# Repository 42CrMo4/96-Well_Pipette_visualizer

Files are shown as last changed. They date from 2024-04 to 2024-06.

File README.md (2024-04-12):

# KiCad_Template

This is a template repo for KiCAD v6 projects with 

### Goal & Status
| undefined | learn | prototype | 80-20-rule | polished Product |
|---|---|---|---|---|
| not known what the project will bring | personally learn something new (function, design, process) otherwise no usefull outcome expected | a working prototype or mvp | 80% outcome with 20% effort. Dont expect a finished product. | - |

| idea | design | implementation | testing | finished |
|---|---|---|---|---|
| brainstorming workflow | putting together a goal list, architecture, hig level | schematic, pcb | | |

## Todo

* ~add DRC, ERC as seperate WF~ 
* ~add DRC, ERC to release WF as blocking~
* ~add release checklist~
* order release checklist
* ~add workflow to automatically create new realease checklist and realease note file and reset the generic for the next release~
* ~Rename artefacts with project name and date?~
* Add diffrent PCB manufactures output via kibot
* ~Update to kicad6_auto:1.3.0~
* use version number for template

## Usage

hit "use this template" button
delet all unneded files in Doc folder
delet all Schematic stuff but not the text Placeholders <<...>>
delet all PCB stuff but not the text Placeholders <<...>> and the Board Edge (or the iBOM will fail). You can remodel it later.

### Workflow
If not working:
setting -> action -> general -> Workflow permissions -> Read and write permissions

## working

in the first workflow run the action will create a new branch "documentation" to store the newest PCBdraw pictures. 
Each action run will force push the png to this branch. So so not use the Fabrication folder in the documentation branch.

## Description. 

| Font | Back |
|---|---|
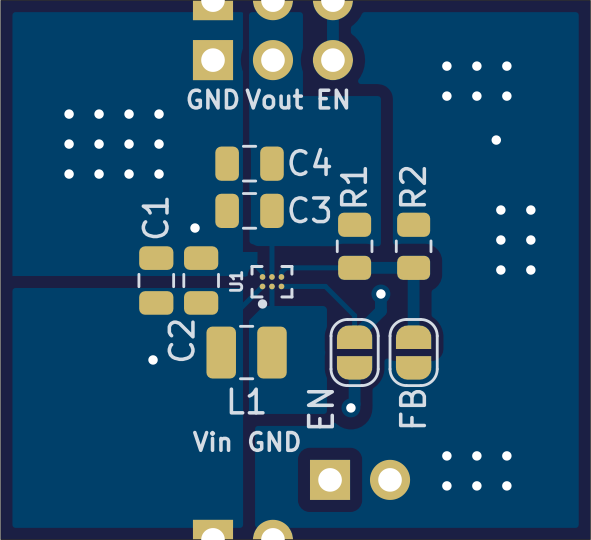
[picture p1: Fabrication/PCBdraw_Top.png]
PCB Top design
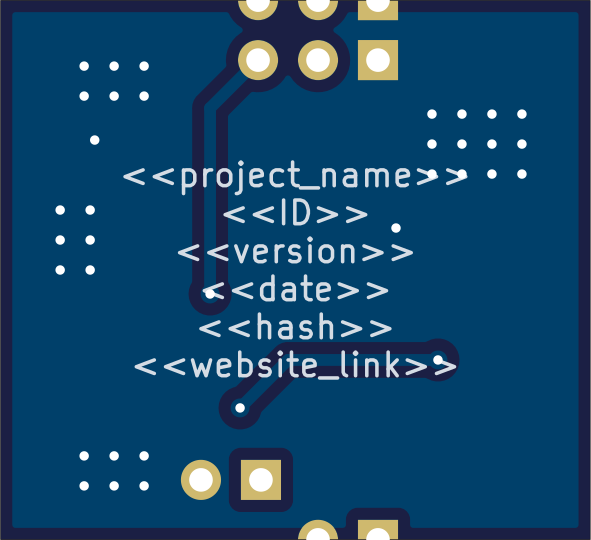
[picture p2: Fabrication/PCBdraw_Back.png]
PCB Back design
|  |  |

Link to the current BOM

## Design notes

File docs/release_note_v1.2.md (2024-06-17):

| Font | Back |
| --- | --- |
|PCB Top design|PCB Back design|

change usb-c shield pads to no net to make kicad happy

Changes
* change usb-c shield pads to <no_net>

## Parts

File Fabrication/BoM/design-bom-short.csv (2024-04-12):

Row | Description | Part | References | Value | Footprint | Quantity Per PCB | Status | Datasheet | STANDARD | PARTREV | MAXIMUM_PACKAGE_HEIGHT | MANUFACTURER
1 | Unpolarized capacitor, small symbol | C_Small | C1 C2 C3 C4 | C_Small | C_0805_2012Metric | 4 |  | ~
2 | Generic connector, single row, 01x02, script generated (kicad-library-utils/schlib/autogen/connector/) | Conn_01x02 | J1 J2 | Conn_01x02 | PinHeader_1x02_P2.54mm_Vertical | 2 |  | ~
3 | Generic connector, single row, 01x03, script generated (kicad-library-utils/schlib/autogen/connector/) | Conn_01x03 | J3 J4 | Conn_01x03 | PinHeader_1x03_P2.54mm_Vertical | 2 |  | ~
4 | Inductor, small symbol | L_Small | L1 | L_Small | L_1008_2520Metric | 1 |  | ~
5 | Resistor, small symbol | R_Small | R1 R2 | R_Small | R_0805_2012Metric | 2 |  | ~
6 |  | TPS61099YFFT | U1 | TPS61099YFFT | BGA6N40P3X2_122X88X62N | 1 |  |  | IPC 7351B | K | 0.625mm | Texas Instruments

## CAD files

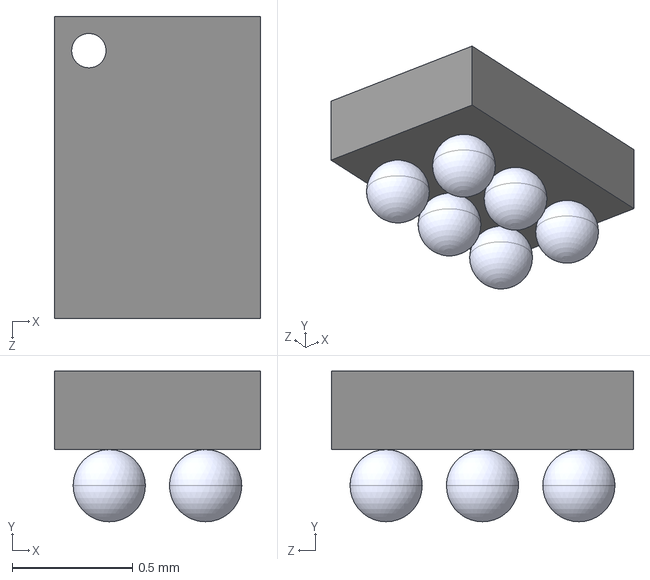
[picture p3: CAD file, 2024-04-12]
3d-models/TPS61099xYFFT.step
0.855 x 0.625 x 1.26 mm

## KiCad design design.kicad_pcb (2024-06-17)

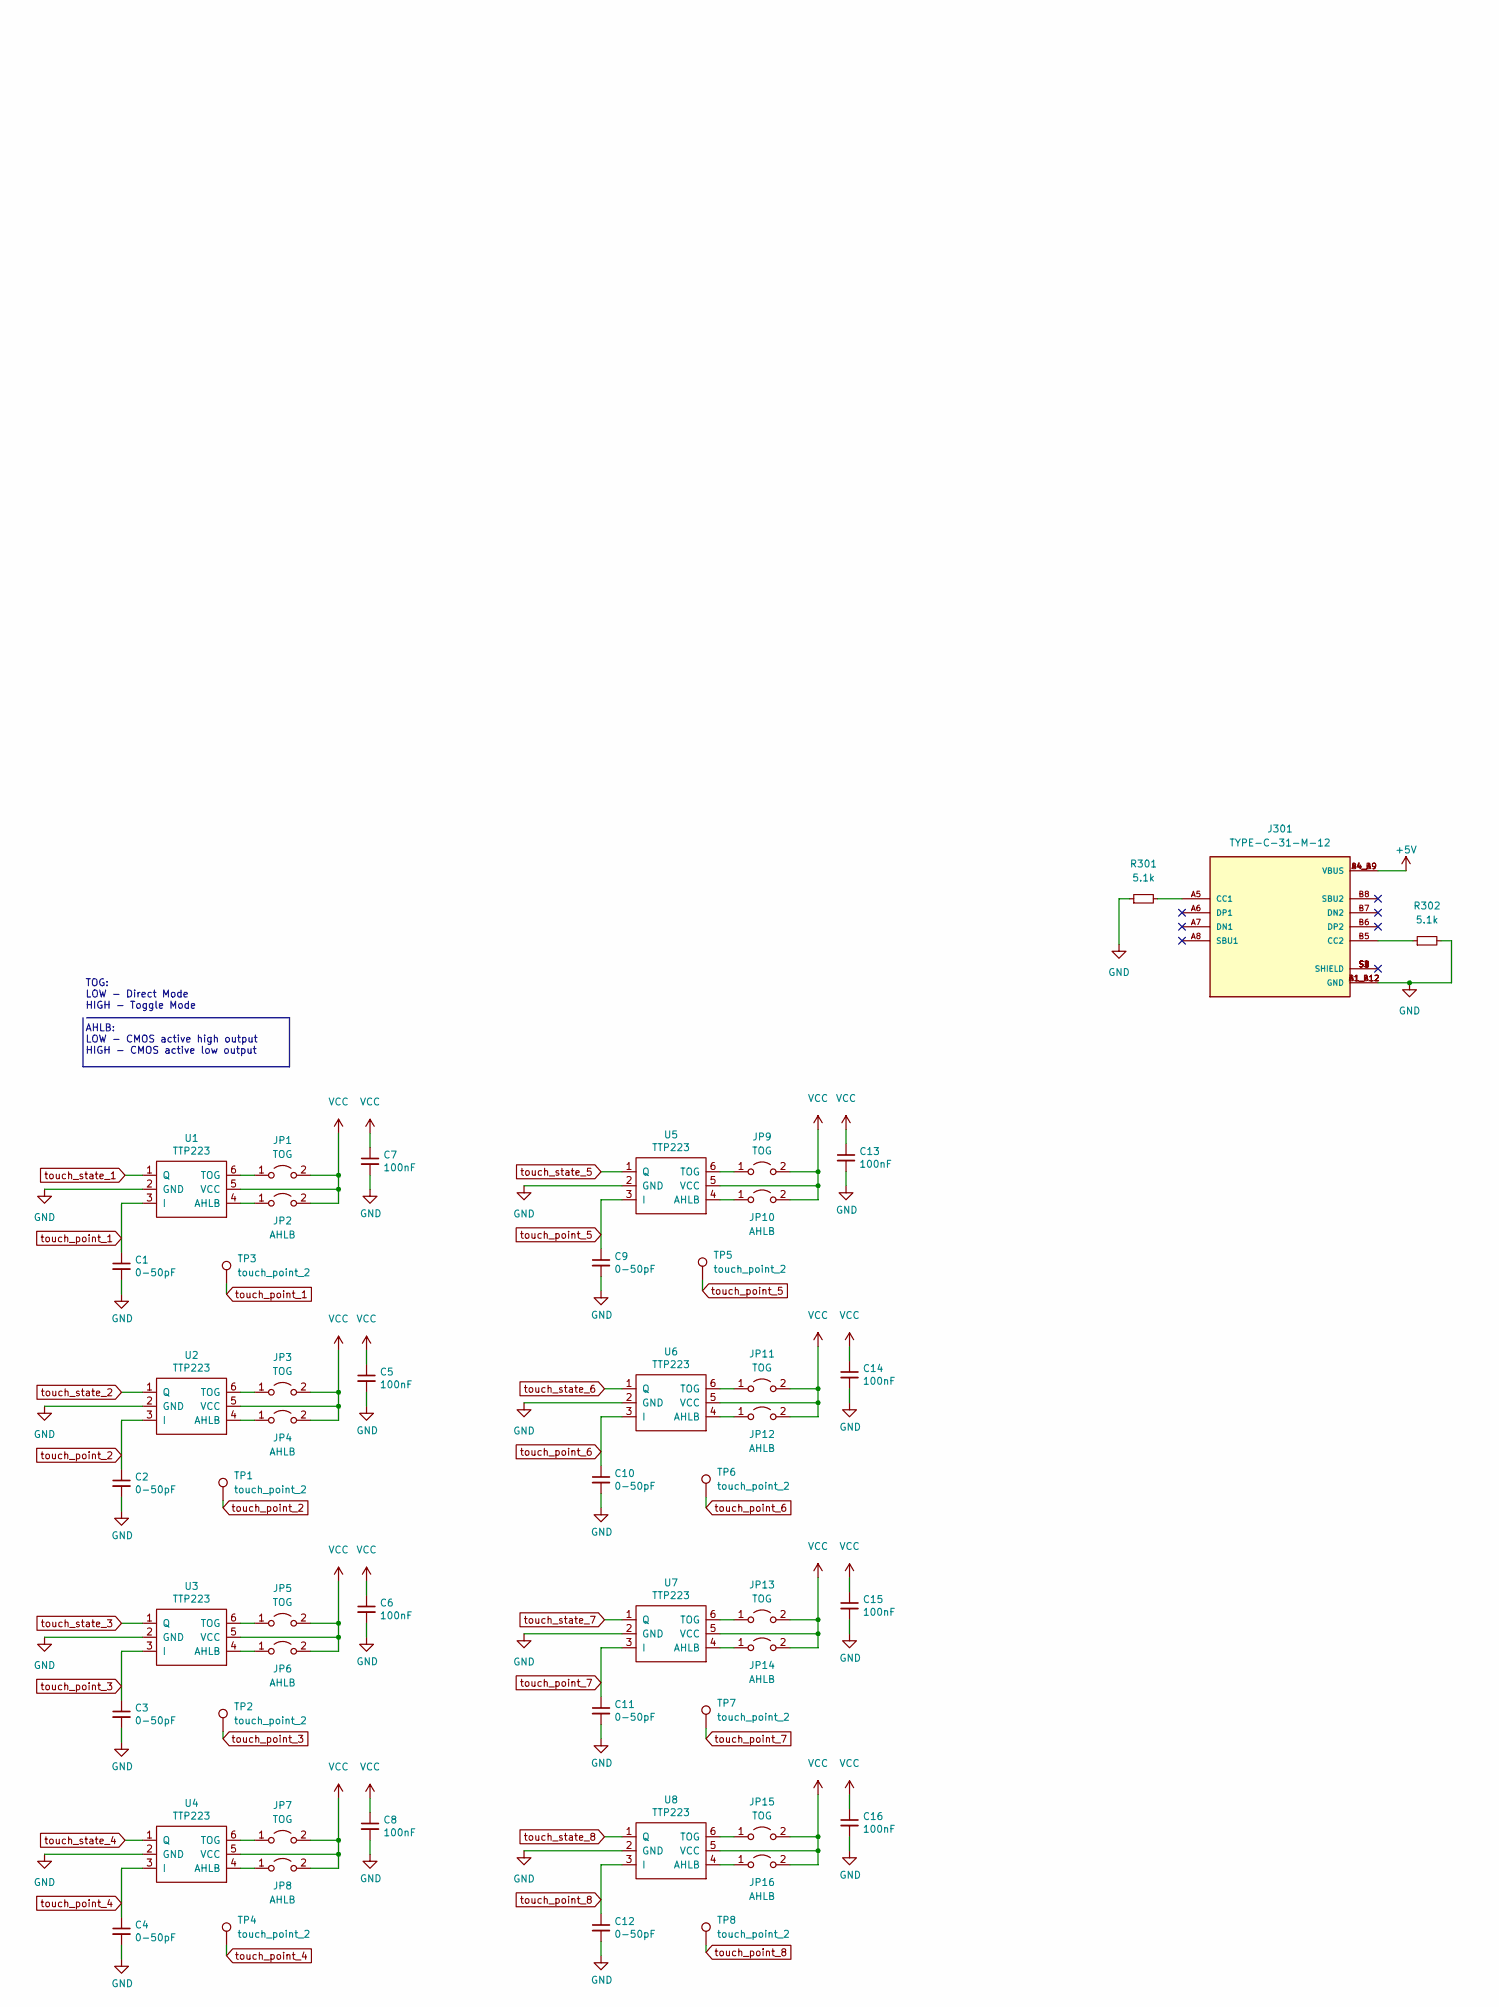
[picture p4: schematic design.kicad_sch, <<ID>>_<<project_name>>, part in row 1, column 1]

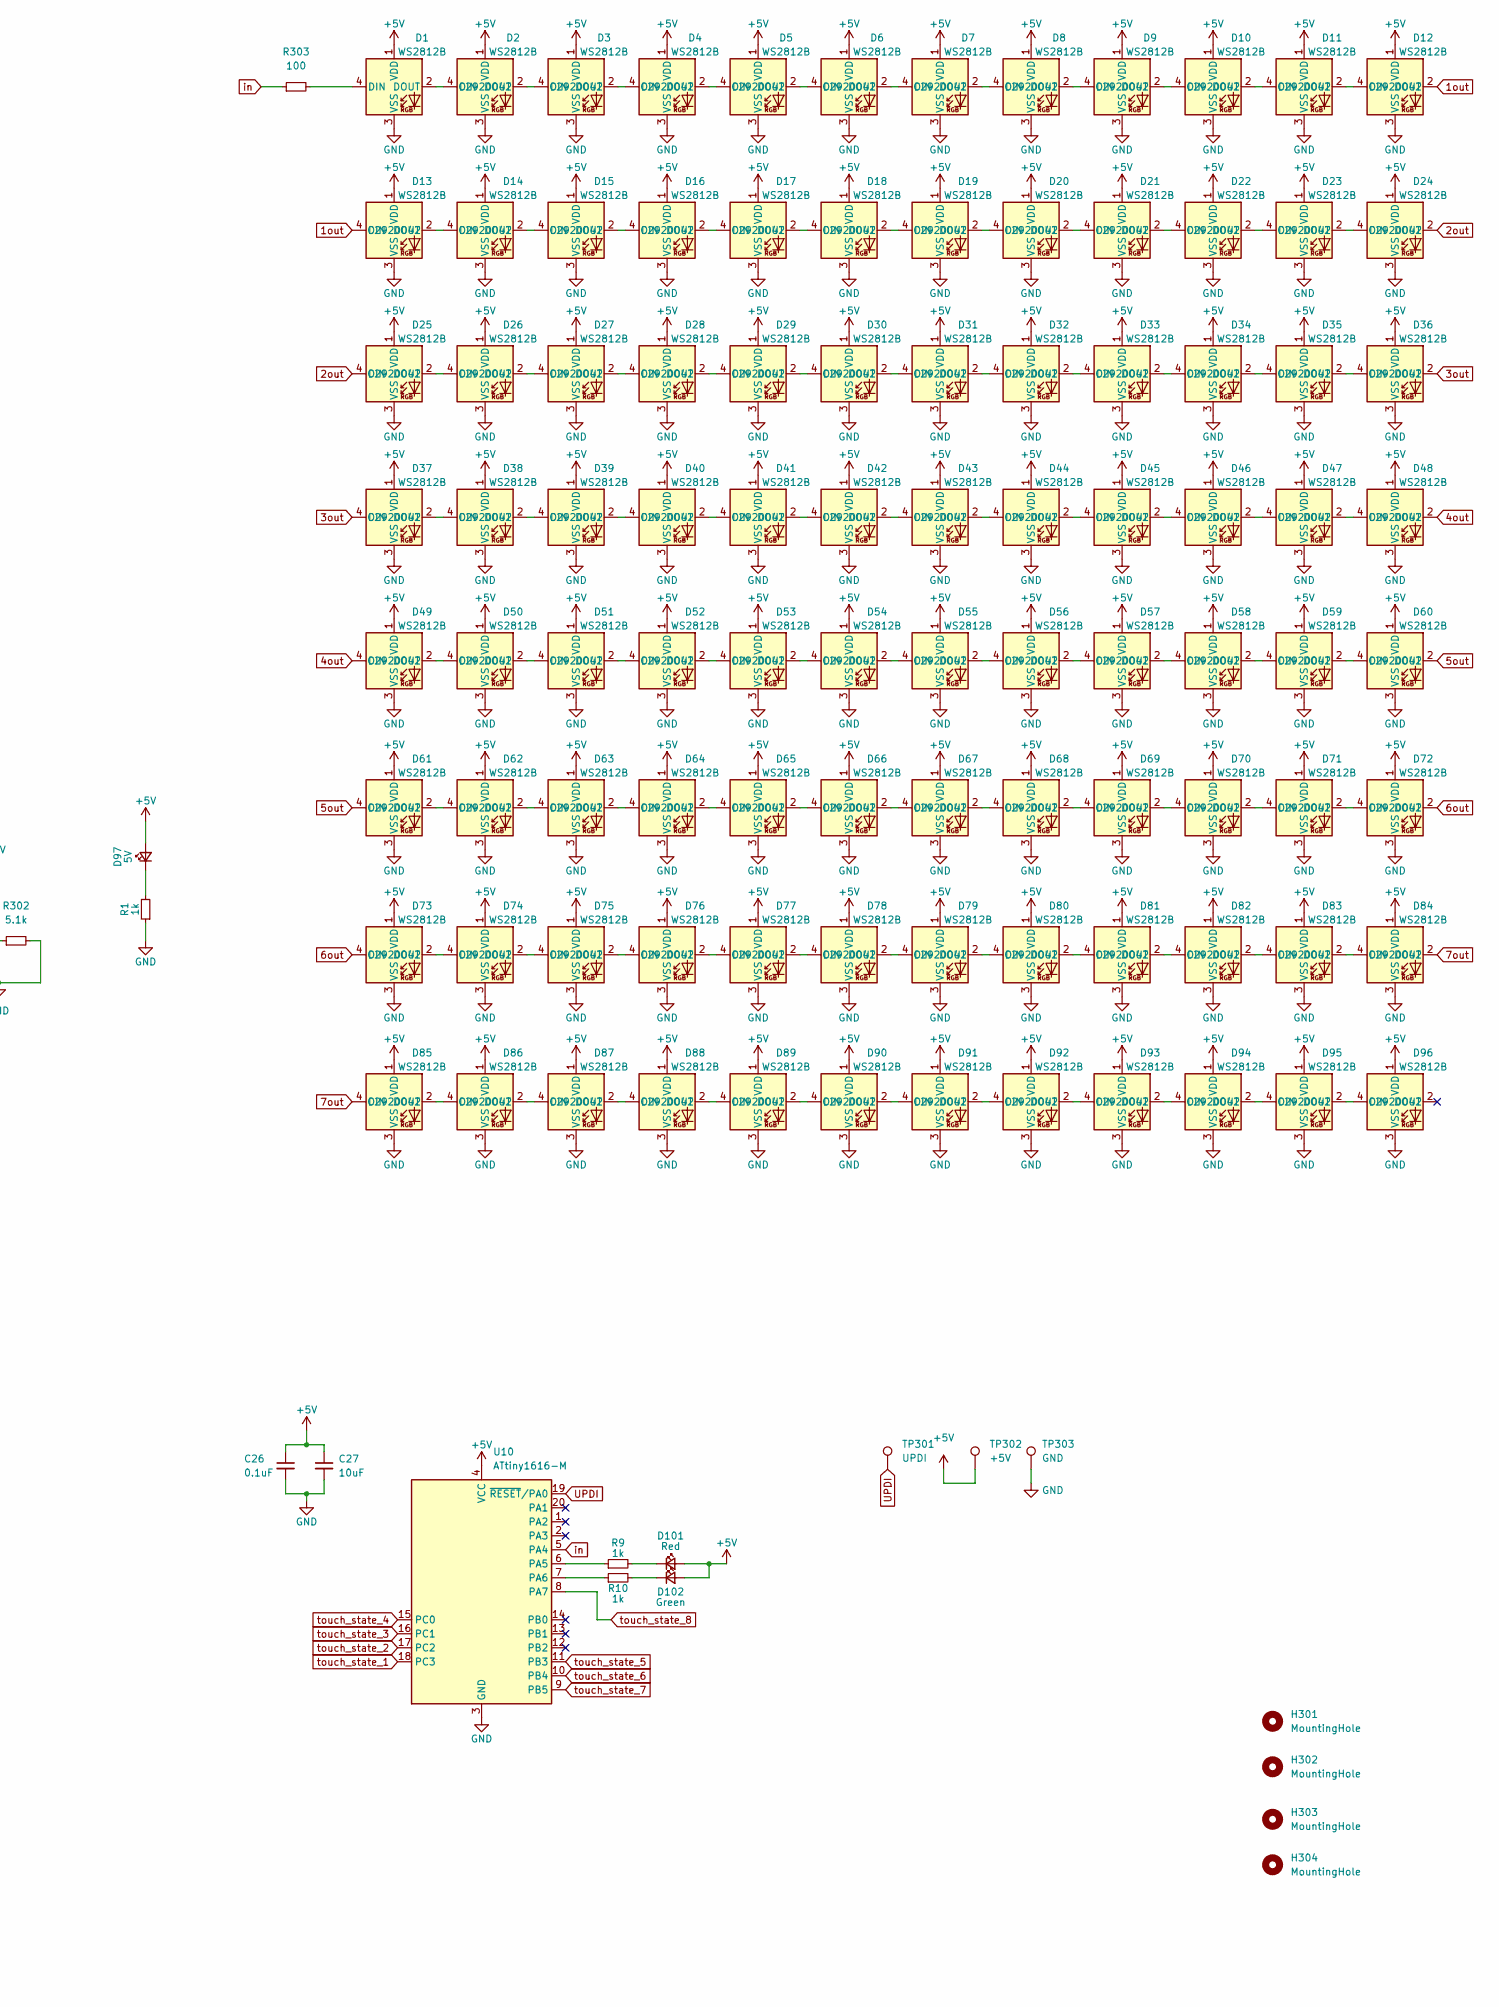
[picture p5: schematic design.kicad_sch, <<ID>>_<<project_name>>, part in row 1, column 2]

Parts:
C1, C2, C3, C4, C9, C10, C11, C12: 0-50pF; C_0805_2012Metric
C5, C6, C7, C8, C13, C14, C15, C16: 100nF; C_0805_2012Metric
C26: 0.1uF; C_0805_2012Metric
C27: 10uF; C_0805_2012Metric
D1, D2, D3, D4, D5, D6, D7, D8, D9, D10, D11, D12, D13, D14, D15, D16, D17, D18, D19, D20, D21, D22, D23, D24, D25, D26, D27, D28, D29, D30, D31, D32, D33, D34, D35, D36, D37, D38, D39, D40, D41, D42, D43, D44, D45, D46, D47, D48, D49, D50, D51, D52, D53, D54, D55, D56, D57, D58, D59, D60, D61, D62, D63, D64, D65, D66, D67, D68, D69, D70, D71, D72, D73, D74, D75, D76, D77, D78, D79, D80, D81, D82, D83, D84, D85, D86, D87, D88, D89, D90, D91, D92, D93, D94, D95, D96: WS2812B; LED_WS2812B_PLCC4_5.0x5.0mm_P3.2mm; LCSC C2920042
D97: 5V; LED_0603_1608Metric
D101: Red; LED_0603_1608Metric
D102: Green; LED_0603_1608Metric
H301, H302, H303, H304: MountingHole; MountingHole_2.7mm_M2.5
J301: TYPE-C-31-M-12; TYPE-C-31-M-12_HRO_TYPE-C-31-M-12; PARTREV 2020.12.08
JP1, JP3, JP5, JP7, JP9, JP11, JP13, JP15: TOG; SolderJumper-2_P1.3mm_Open_RoundedPad1.0x1.5mm
JP2, JP4, JP6, JP8, JP10, JP12, JP14, JP16: AHLB; SolderJumper-2_P1.3mm_Open_RoundedPad1.0x1.5mm
R1, R9, R10: 1k; R_0805_2012Metric
R301, R302: 5.1k; R_0805_2012Metric
R303: 100; R_0805_2012Metric
TP1, TP2, TP3, TP4, TP5, TP6, TP7, TP8: touch_point_2
TP301: UPDI; TestPoint_Pad_3.0x3.0mm
TP302: +5V; TestPoint_Pad_3.0x3.0mm
TP303: GND; TestPoint_Pad_3.0x3.0mm
U1, U2, U3, U4, U5, U6, U7, U8: TTP223; SOT-23-6
U10: ATtiny1616-M; VQFN-20-1EP_3x3mm_P0.4mm_EP1.7x1.7mm

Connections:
1out: D12.2 (DOUT), D13.4 (DIN)
2out: D24.2 (DOUT), D25.4 (DIN)
3out: D36.2 (DOUT), D37.4 (DIN)
4out: D48.2 (DOUT), D49.4 (DIN)
5out: D60.2 (DOUT), D61.4 (DIN)
6out: D72.2 (DOUT), D73.4 (DIN)
7out: D84.2 (DOUT), D85.4 (DIN)
GND: C1.2, C2.2, C3.2, C4.2, C5.2, C6.2, C7.2, C8.2, C9.2, C10.2, C11.2, C12.2, C13.2, C14.2, C15.2, C16.2, C26.2, C27.2, D1.3 (VSS), D2.3 (VSS), D3.3 (VSS), D4.3 (VSS), D5.3 (VSS), D6.3 (VSS), D7.3 (VSS), D8.3 (VSS), D9.3 (VSS), D10.3 (VSS), D11.3 (VSS), D12.3 (VSS), D13.3 (VSS), D14.3 (VSS), D15.3 (VSS), D16.3 (VSS), D17.3 (VSS), D18.3 (VSS), D19.3 (VSS), D20.3 (VSS), D21.3 (VSS), D22.3 (VSS), D23.3 (VSS), D24.3 (VSS), D25.3 (VSS), D26.3 (VSS), D27.3 (VSS), D28.3 (VSS), D29.3 (VSS), D30.3 (VSS), D31.3 (VSS), D32.3 (VSS), D33.3 (VSS), D34.3 (VSS), D35.3 (VSS), D36.3 (VSS), D37.3 (VSS), D38.3 (VSS), D39.3 (VSS), D40.3 (VSS), D41.3 (VSS), D42.3 (VSS), D43.3 (VSS), D44.3 (VSS), D45.3 (VSS), D46.3 (VSS), D47.3 (VSS), D48.3 (VSS), D49.3 (VSS), D50.3 (VSS), D51.3 (VSS), D52.3 (VSS), D53.3 (VSS), D54.3 (VSS), D55.3 (VSS), D56.3 (VSS), D57.3 (VSS), D58.3 (VSS), D59.3 (VSS), D60.3 (VSS), D61.3 (VSS), D62.3 (VSS), D63.3 (VSS), D64.3 (VSS), D65.3 (VSS), D66.3 (VSS), D67.3 (VSS), D68.3 (VSS), D69.3 (VSS), D70.3 (VSS), D71.3 (VSS), D72.3 (VSS), D73.3 (VSS), D74.3 (VSS), D75.3 (VSS), D76.3 (VSS), D77.3 (VSS), D78.3 (VSS), D79.3 (VSS), D80.3 (VSS), D81.3 (VSS), D82.3 (VSS), D83.3 (VSS), D84.3 (VSS), D85.3 (VSS), D86.3 (VSS), D87.3 (VSS), D88.3 (VSS), D89.3 (VSS), D90.3 (VSS), D91.3 (VSS), D92.3 (VSS), D93.3 (VSS), D94.3 (VSS), D95.3 (VSS), D96.3 (VSS), J301.A1_B12 (GND), J301.B1_A12 (GND), R1.1, R301.1, R302.2, TP303.1, U1.2 (GND), U2.2 (GND), U3.2 (GND), U4.2 (GND), U5.2 (GND), U6.2 (GND), U7.2 (GND), U8.2 (GND), U10.3 (GND), U10.21 (GND)
unnamed: D1.2 (DOUT), D2.4 (DIN)
unnamed: D1.4 (DIN), R303.2
unnamed: D2.2 (DOUT), D3.4 (DIN)
unnamed: D3.2 (DOUT), D4.4 (DIN)
unnamed: D4.2 (DOUT), D5.4 (DIN)
unnamed: D5.2 (DOUT), D6.4 (DIN)
unnamed: D6.2 (DOUT), D7.4 (DIN)
unnamed: D7.2 (DOUT), D8.4 (DIN)
unnamed: D8.2 (DOUT), D9.4 (DIN)
unnamed: D10.2 (DOUT), D11.4 (DIN)
unnamed: D9.2 (DOUT), D10.4 (DIN)
unnamed: D11.2 (DOUT), D12.4 (DIN)
unnamed: D13.2 (DOUT), D14.4 (DIN)
unnamed: D14.2 (DOUT), D15.4 (DIN)
unnamed: D15.2 (DOUT), D16.4 (DIN)
unnamed: D16.2 (DOUT), D17.4 (DIN)
unnamed: D17.2 (DOUT), D18.4 (DIN)
unnamed: D18.2 (DOUT), D19.4 (DIN)
unnamed: D19.2 (DOUT), D20.4 (DIN)
unnamed: D20.2 (DOUT), D21.4 (DIN)
unnamed: D21.2 (DOUT), D22.4 (DIN)
unnamed: D22.2 (DOUT), D23.4 (DIN)
unnamed: D23.2 (DOUT), D24.4 (DIN)
unnamed: D25.2 (DOUT), D26.4 (DIN)
unnamed: D26.2 (DOUT), D27.4 (DIN)
unnamed: D27.2 (DOUT), D28.4 (DIN)
unnamed: D28.2 (DOUT), D29.4 (DIN)
unnamed: D29.2 (DOUT), D30.4 (DIN)
unnamed: D30.2 (DOUT), D31.4 (DIN)
unnamed: D31.2 (DOUT), D32.4 (DIN)
unnamed: D32.2 (DOUT), D33.4 (DIN)
unnamed: D33.2 (DOUT), D34.4 (DIN)
unnamed: D34.2 (DOUT), D35.4 (DIN)
unnamed: D35.2 (DOUT), D36.4 (DIN)
unnamed: D37.2 (DOUT), D38.4 (DIN)
unnamed: D38.2 (DOUT), D39.4 (DIN)
unnamed: D39.2 (DOUT), D40.4 (DIN)
unnamed: D40.2 (DOUT), D41.4 (DIN)
unnamed: D41.2 (DOUT), D42.4 (DIN)
unnamed: D42.2 (DOUT), D43.4 (DIN)
unnamed: D43.2 (DOUT), D44.4 (DIN)
unnamed: D44.2 (DOUT), D45.4 (DIN)
unnamed: D45.2 (DOUT), D46.4 (DIN)
unnamed: D46.2 (DOUT), D47.4 (DIN)
unnamed: D47.2 (DOUT), D48.4 (DIN)
unnamed: D49.2 (DOUT), D50.4 (DIN)
unnamed: D50.2 (DOUT), D51.4 (DIN)
unnamed: D51.2 (DOUT), D52.4 (DIN)
unnamed: D52.2 (DOUT), D53.4 (DIN)
unnamed: D53.2 (DOUT), D54.4 (DIN)
unnamed: D54.2 (DOUT), D55.4 (DIN)
unnamed: D55.2 (DOUT), D56.4 (DIN)
unnamed: D56.2 (DOUT), D57.4 (DIN)
unnamed: D57.2 (DOUT), D58.4 (DIN)
unnamed: D58.2 (DOUT), D59.4 (DIN)
unnamed: D59.2 (DOUT), D60.4 (DIN)
unnamed: D61.2 (DOUT), D62.4 (DIN)
unnamed: D62.2 (DOUT), D63.4 (DIN)
unnamed: D63.2 (DOUT), D64.4 (DIN)
unnamed: D64.2 (DOUT), D65.4 (DIN)
unnamed: D65.2 (DOUT), D66.4 (DIN)
unnamed: D66.2 (DOUT), D67.4 (DIN)
unnamed: D67.2 (DOUT), D68.4 (DIN)
unnamed: D68.2 (DOUT), D69.4 (DIN)
unnamed: D69.2 (DOUT), D70.4 (DIN)
unnamed: D70.2 (DOUT), D71.4 (DIN)
unnamed: D71.2 (DOUT), D72.4 (DIN)
unnamed: D73.2 (DOUT), D74.4 (DIN)
unnamed: D74.2 (DOUT), D75.4 (DIN)
unnamed: D75.2 (DOUT), D76.4 (DIN)
unnamed: D76.2 (DOUT), D77.4 (DIN)
unnamed: D77.2 (DOUT), D78.4 (DIN)
unnamed: D78.2 (DOUT), D79.4 (DIN)
unnamed: D79.2 (DOUT), D80.4 (DIN)
unnamed: D80.2 (DOUT), D81.4 (DIN)
unnamed: D81.2 (DOUT), D82.4 (DIN)
unnamed: D82.2 (DOUT), D83.4 (DIN)
unnamed: D83.2 (DOUT), D84.4 (DIN)
unnamed: D85.2 (DOUT), D86.4 (DIN)
unnamed: D86.2 (DOUT), D87.4 (DIN)
unnamed: D87.2 (DOUT), D88.4 (DIN)
unnamed: D88.2 (DOUT), D89.4 (DIN)
unnamed: D89.2 (DOUT), D90.4 (DIN)
unnamed: D90.2 (DOUT), D91.4 (DIN)
unnamed: D91.2 (DOUT), D92.4 (DIN)
unnamed: D92.2 (DOUT), D93.4 (DIN)
unnamed: D93.2 (DOUT), D94.4 (DIN)
unnamed: D94.2 (DOUT), D95.4 (DIN)
unnamed: D95.2 (DOUT), D96.4 (DIN)
unnamed: D97.1 (K), R1.2
unnamed: D101.1 (K), R9.2
unnamed: D102.1 (K), R10.2
unnamed: J301.A5 (CC1), R301.2
unnamed: J301.B5 (CC2), R302.1
unnamed: JP1.1 (A), U1.6 (TOG)
unnamed: JP2.1 (A), U1.4 (AHLB)
unnamed: JP3.1 (A), U2.6 (TOG)
unnamed: JP4.1 (A), U2.4 (AHLB)
unnamed: JP5.1 (A), U3.6 (TOG)
unnamed: JP6.1 (A), U3.4 (AHLB)
unnamed: JP7.1 (A), U4.6 (TOG)
unnamed: JP8.1 (A), U4.4 (AHLB)
unnamed: JP9.1 (A), U5.6 (TOG)
unnamed: JP10.1 (A), U5.4 (AHLB)
unnamed: JP11.1 (A), U6.6 (TOG)
unnamed: JP12.1 (A), U6.4 (AHLB)
unnamed: JP13.1 (A), U7.6 (TOG)
unnamed: JP14.1 (A), U7.4 (AHLB)
unnamed: JP15.1 (A), U8.6 (TOG)
unnamed: JP16.1 (A), U8.4 (AHLB)
unnamed: R9.1, U10.6 (PA5)
unnamed: R10.1, U10.7 (PA6)
UPDI: TP301.1, U10.19 (~RESET/PA0)
in: R303.1, U10.5 (PA4)
touch_point_1: C1.1, TP3.1, U1.3 (I)
touch_point_2: C2.1, TP1.1, U2.3 (I)
touch_point_3: C3.1, TP2.1, U3.3 (I)
touch_point_4: C4.1, TP4.1, U4.3 (I)
touch_point_5: C9.1, TP5.1, U5.3 (I)
touch_point_6: C10.1, TP6.1, U6.3 (I)
touch_point_7: C11.1, TP7.1, U7.3 (I)
touch_point_8: C12.1, TP8.1, U8.3 (I)
touch_state_1: U1.1 (Q), U10.18 (PC3)
touch_state_2: U2.1 (Q), U10.17 (PC2)
touch_state_3: U3.1 (Q), U10.16 (PC1)
touch_state_4: U4.1 (Q), U10.15 (PC0)
touch_state_5: U5.1 (Q), U10.11 (PB3)
touch_state_6: U6.1 (Q), U10.10 (PB4)
touch_state_7: U7.1 (Q), U10.9 (PB5)
touch_state_8: U8.1 (Q), U10.8 (PA7)

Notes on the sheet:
TOG: LOW - Direct Mode HIGH - Toggle Mode AHLB: LOW - CMOS active high output HIGH - CMOS active low output

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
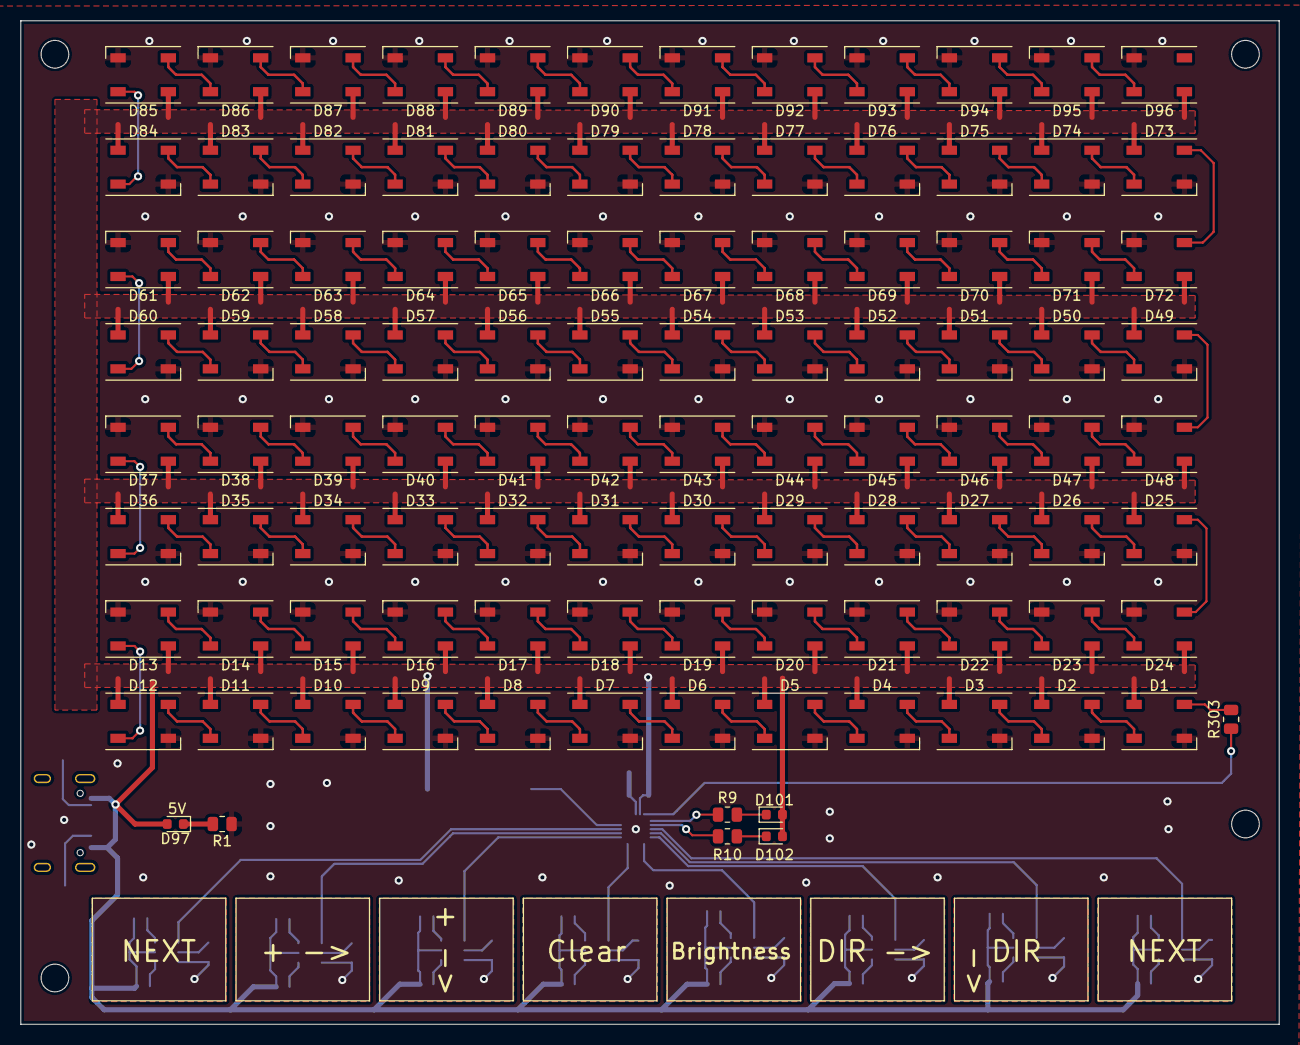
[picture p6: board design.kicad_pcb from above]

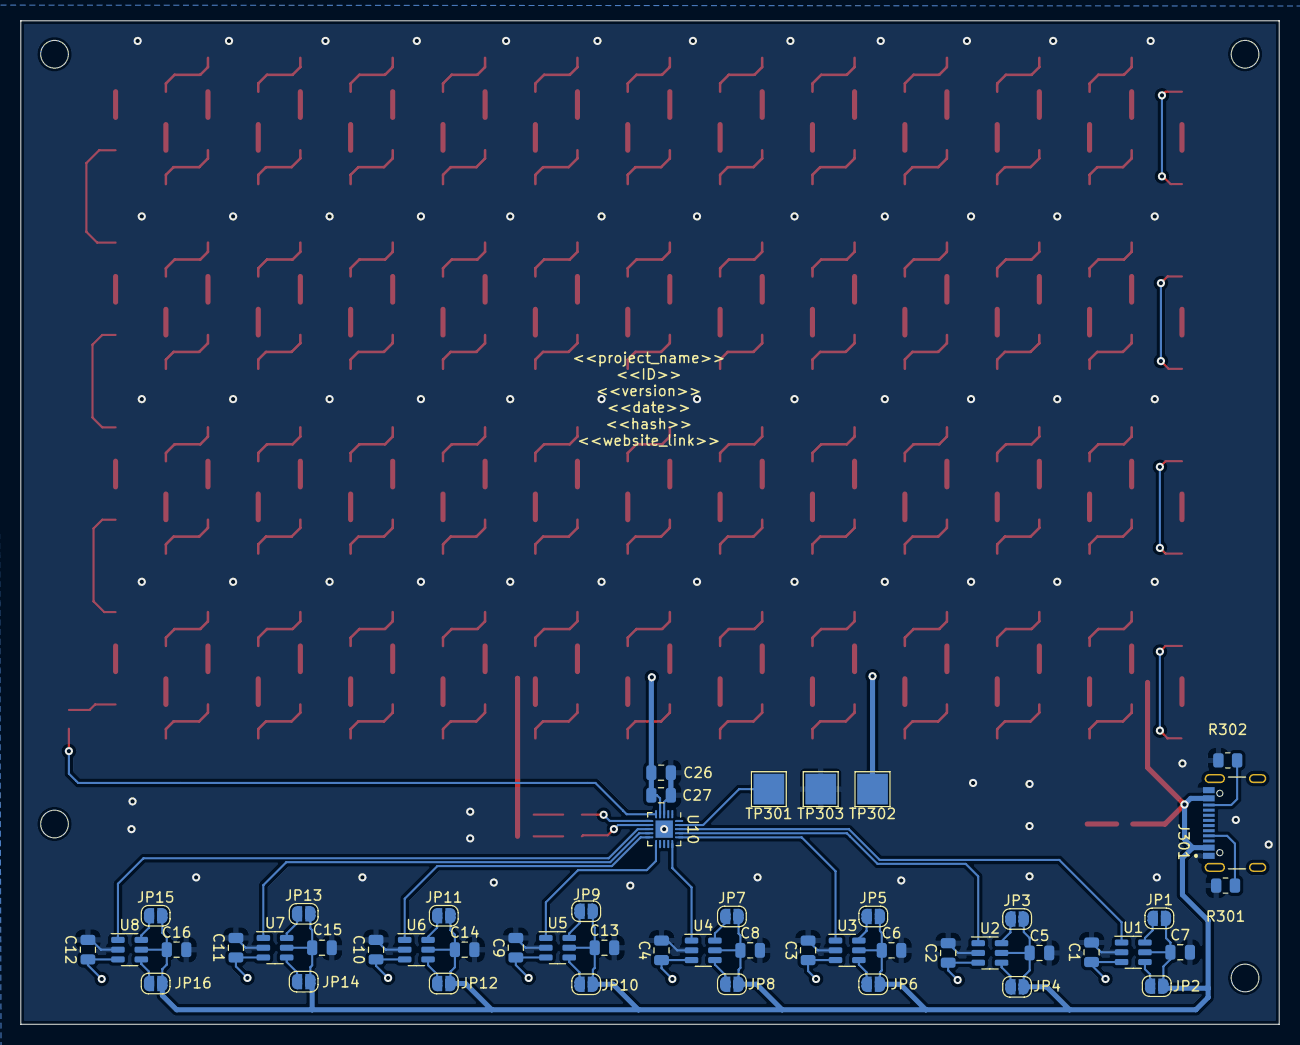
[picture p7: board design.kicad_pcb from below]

Board: 2 copper layers, 122.6 x 97.8 mm, 156 parts (49 on the bottom side), 139 nets.

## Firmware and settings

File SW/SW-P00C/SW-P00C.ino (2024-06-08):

// HW Version v1.0 

#include <Adafruit_NeoPixel.h>
#include "matrix.h"

// Pin where the LED strip is connected
#define LED_PIN 3

// Pins where the buttons are connected
#define BUTTON_PIN 4
#define BUTTON2_PIN 9
#define BRIGHTNESS_BUTTON_PIN 6
#define NUM_LEDS_LIT_BUTTON_PIN 8
#define COLOR_BUTTON_PIN 5
#define CLEAR_BUTTON_PIN 7

// Number of LEDs in the strip
#define NUM_LEDS 96

// Array of possible numbers of LEDs to light up at a time
const int numLEDsLitOptions[] = {1, 2, 3, 4, 6};
const int numNumLEDsLitOptions = sizeof(numLEDsLitOptions) / sizeof(numLEDsLitOptions[0]);
int currentNumLEDsLitIndex = 0;

int numLEDsLit = numLEDsLitOptions[currentNumLEDsLitIndex];

static int startIndex = 0;

// Brightness levels
const int brightnessLevels[] = {10, 30, 50, 80, 100};
const int numBrightnessLevels = sizeof(brightnessLevels) / sizeof(brightnessLevels[0]);
int currentBrightnessIndex = 0;

// Create an instance of the Adafruit_NeoPixel class
Adafruit_NeoPixel strip = Adafruit_NeoPixel(NUM_LEDS, LED_PIN, NEO_GRB + NEO_KHZ800);

// Colors
const uint32_t colors[] = {
  strip.Color(20, 0, 0), // Red
  strip.Color(0, 20, 0), // Green
  strip.Color(0, 0, 20)  // Blue
};
const int numColors = sizeof(colors) / sizeof(colors[0]);
int currentColorIndex = 0;

// Function to set a specific LED in the strip
void setLED(int row, int col, uint32_t color) {
  if (row >= 0 && row < rows && col >= 0 && col < cols) {
    int ledIndex = matrix[row][col];
    strip.setPixelColor(ledIndex, color);
  }
}

// Function to light up LEDs based on the numLEDsLit variable and start position
void lightUpMatrix(int startIndex) {
  // Turn off all LEDs initially
  strip.clear();
  
  int count = 0;

  // Calculate the starting row and column based on startIndex
  for (int i = 0; i < rows; i++) {
    for (int j = 0; j < cols; j++) {
      int currentIndex = i * cols + j;
      if (currentIndex >= startIndex && count < numLEDsLit) {
        setLED(i, j, colors[currentColorIndex]); // Set each LED to the current color
        count++;
      }
    }
  }
  strip.show();
}

// Function to set brightness
void setBrightness() {
  uint8_t brightness = map(brightnessLevels[currentBrightnessIndex], 0, 100, 0, 255);
  strip.setBrightness(brightness);
  strip.show(); // Update the strip with the new brightness
}

// Function to set the number of LEDs lit
void setNumLEDsLit() {
  numLEDsLit = numLEDsLitOptions[currentNumLEDsLitIndex];
}

void setup() {
  // Initialize the LED strip
  strip.begin();
  strip.show(); // Initialize all pixels to 'off'

  // Initialize the button pins as input with internal pull-up resistors
  pinMode(BUTTON_PIN, INPUT_PULLUP);
  pinMode(BRIGHTNESS_BUTTON_PIN, INPUT_PULLUP);
  pinMode(NUM_LEDS_LIT_BUTTON_PIN, INPUT_PULLUP);
  pinMode(COLOR_BUTTON_PIN, INPUT_PULLUP);
  pinMode(CLEAR_BUTTON_PIN, INPUT_PULLUP);

  // Set initial brightness
  setBrightness();

  // Initial light up matrix
  lightUpMatrix(startIndex);
}

void loop() {
  static bool buttonPressed = false;
  static bool brightnessButtonPressed = false;
  static bool numLEDsLitButtonPressed = false;
  static bool colorButtonPressed = false;
  static bool clearButtonPressed = false;

  static bool canChangeNumLEDsLit = true; // Flag to allow changing numLEDsLit only at start and after clear

  // Check if the main button is pressed
  if (digitalRead(BUTTON_PIN) == LOW || digitalRead(BUTTON2_PIN) == LOW) {
    // Debounce the button press
    if (!buttonPressed) {
      buttonPressed = true;

      // Light up the matrix starting from the current startIndex
      lightUpMatrix(startIndex);

      // Advance the startIndex to the next position
      startIndex += numLEDsLit;
      if (startIndex >= NUM_LEDS) {
        startIndex = 0; // Reset to the beginning
      }

      // Disallow changing numLEDsLit after the first press
      canChangeNumLEDsLit = false;
    }
  } else {
    buttonPressed = false;
  }

  // Check if the brightness button is pressed
  if (digitalRead(BRIGHTNESS_BUTTON_PIN) == LOW) {
    // Debounce the brightness button press
    if (!brightnessButtonPressed) {
      brightnessButtonPressed = true;

      // Advance to the next brightness level
      currentBrightnessIndex = (currentBrightnessIndex + 1) % numBrightnessLevels;
      
      // Set the new brightness immediately
      setBrightness();
    }
  } else {
    brightnessButtonPressed = false;
  }

  // Check if the numLEDsLit button is pressed
  if (digitalRead(NUM_LEDS_LIT_BUTTON_PIN) == LOW && canChangeNumLEDsLit) {
    // Debounce the numLEDsLit button press
    if (!numLEDsLitButtonPressed) {
      numLEDsLitButtonPressed = true;

      // Advance to the next numLEDsLit option
      currentNumLEDsLitIndex = (currentNumLEDsLitIndex + 1) % numNumLEDsLitOptions;

      // Set the new numLEDsLit value immediately
      setNumLEDsLit();

      // Update the matrix immediately
      lightUpMatrix(startIndex);
    }
  } else {
    numLEDsLitButtonPressed = false;
  }

  // Check if the color button is pressed
  if (digitalRead(COLOR_BUTTON_PIN) == LOW) {
    // Debounce the color button press
    if (!colorButtonPressed) {
      colorButtonPressed = true;

      // Advance to the next color
      currentColorIndex = (currentColorIndex + 1) % numColors;

      // Set the new color immediately
      lightUpMatrix(startIndex - numLEDsLit);
    }
  } else {
    colorButtonPressed = false;
  }

  // Check if the clear button is pressed
  if (digitalRead(CLEAR_BUTTON_PIN) == LOW) {
    // Debounce the clear button press
    if (!clearButtonPressed) {
      clearButtonPressed = true;

      // Clear the matrix and reset startIndex
      startIndex = 0;
      strip.clear();
      strip.show();

      // Allow changing numLEDsLit after clearing
      canChangeNumLEDsLit = true;

      // Light up the first LEDs again
      lightUpMatrix(startIndex);
    }
  } else {
    clearButtonPressed = false;
  }
}

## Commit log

2024-05-06 change to QFN 1616
    [design.kicad_pcb, design.kicad_sch]
2024-05-18 some confusing LED double footprints
    [design.kicad_pcb, design.kicad_sch]
2024-05-18 new layout
    [design.kicad_pcb, design.kicad_sch]
2024-05-18 use kicad 8 branch of workflow
2024-05-18 added lcsc number test
    [design.kicad_sch]
2024-05-18 update all LEDs with LCSC #
    [design.kicad_sch]
2024-05-19 mounting holes
    [design.kicad_pcb, design.kicad_sch]
2024-05-19 Test Ausrichtung
    [design.kicad_pcb]
2024-05-19 mounting hole
    [design.kicad_pcb]
2024-05-19 silkscreen correction
    [design.kicad_pcb]
2024-06-06 start to implement the button press feature
2024-06-06 Add simulated button press over UART
    Updated the code to include functionality for simulating a button press via UART. Now, besides physical button presses on pin 4, the program also responds to the character 'p' received over serial co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
2024-06-06 Factor out LED matrix definition to a separate file
    Created matrix.h to define the LED matrix separately from the main code. Updated the main code to reference the matrix from matrix.h, improving modularity and readability.
2024-06-06 Add brightness control via button and serial input
    Updated the code to include functionality for toggling between different brightness levels (10, 30, 50, 80, 100) using a second button and serial input. Added definitions for the brightness button an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
2024-06-06 Fix brightness control in lightUpMatrix function
    Updated the lightUpMatrix function to properly set brightness based on the currentBrightnessIndex. The brightness value is now correctly mapped and passed to the strip.setBrightness() call, ensuring it affects the LED strip.
    [SW-P00C.ino]
2024-06-06 Fix brightness setting and update immediately
    Modified the lightUpMatrix function to set the brightness after setting LED colors. Added a setBrightness function to update the brightness immediately when the brightness button is pressed, ensuring changes take effect without waiting for the next button press.
    [SW-P00C.ino]
2024-06-06 Refactor brightness control and immediate brightness update
    Refactored the code to ensure the brightness is set immediately when toggled, rather than after the next button press. Improved function placement and clarity for setting the brightness and lighting 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
2024-06-06 Add button and serial option to toggle the number of LEDs lit
    Added a new button and serial option to toggle the "numLEDsLit" variable between the values 1, 2, 3, and 4. Updated the loop function to handle this new input and update the number of LEDs lit accord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
2024-06-06 Update numLEDsLit immediately when button is pressed
    Fixed the issue where the change in the number of LEDs lit was only visible after changing to the next set of LEDs. The update is now immediate upon button press or serial command.
    [SW-P00C.ino]
2024-06-06 Add color change and clear matrix functionality
    Added functionality to change LED colors between red, green, and blue using a button or serial command. Also added a button and serial command to clear the matrix and start over.
2024-06-08 Refactor and enhance LED matrix control with button-only inputs
    - Removed all serial read functionality and handling to focus on button inputs for control.
2024-06-08 Fix color change behavior and update with button-only inputs
    - Enhanced color change functionality to not advance to the next LEDs, retaining the current LED position.
    [SW-P00C.ino]
2024-06-08 light up first led(s) after clear
2024-06-08 add numLEDsLitOption with 6 LEDs
2024-06-08 add the other next button, update pins for pro mini
2024-06-17 changed VCC to +5V and connect them
    [design.kicad_pcb, design.kicad_sch]
2024-06-17 add series resistor
    closes #2
    [design.kicad_pcb, design.kicad_sch]
2024-06-17 cange usb-c footprints soldermask. add connections to shield.
    [design.kicad_pcb]
2024-06-17 USB-C move shield to no NET
    [design.kicad_pcb]
